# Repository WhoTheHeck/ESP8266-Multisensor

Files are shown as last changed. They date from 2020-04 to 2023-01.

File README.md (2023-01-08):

# ESPHome based multisensor



## Overview

Multisensor measuring temperature, humidity, air quality, brightness and movement. ESP board is a NodeMCU v2; Sensors are: SHT31, CCS811, BH1750 and AM312. An RGB LED indicates the air quality (good to bad or high humidity) whenever movement is detected. Using 3pin JST connectors three external sensors, running off of 3V can be attached. Two are digital only, one can be analog.
Components fit a standard 70x50mm prototype PCB. If you are the super-DIY-person everything can be soldered and wired up on a prototype PCB. If you want to avoid soldering too much and want to avoid wiring mistakes grab the PCB files, get PCBs manufactured and only solder the sensor modules.  



## Case

Case is intended to be 3d printed. Sensors sit in indentations in printed top part, which requires lots of support structures for 3D printing. A simplified version that can be printed upside down is possible, but looks less nice. The case measures 76x56x20mm. Everything gets soldered onto the PCB, placed into the case, backside gets screwed onto the wall, frontcase snapfits in place.  



## PCB

The PCB was intended to be hand solderable on a 70x50mm prototype-PCB. It's possible but time consuming. If more than one or two boards are required consider sending PCB files to a manufacturer of your choice. Therefore, the traces are held compatible to be used as an exact hand solder guide and are also fabrication ready. That results in some unnecessary vias.
Dependent on the position of a component hand soldering starts from one or the other side and sometimes an immediate layer change is required. For a manufactured board these additional vias are no problem.
A jumper can be used for changing one of the external sensors from digital to analog-in.

For manual soldering top traces are:  
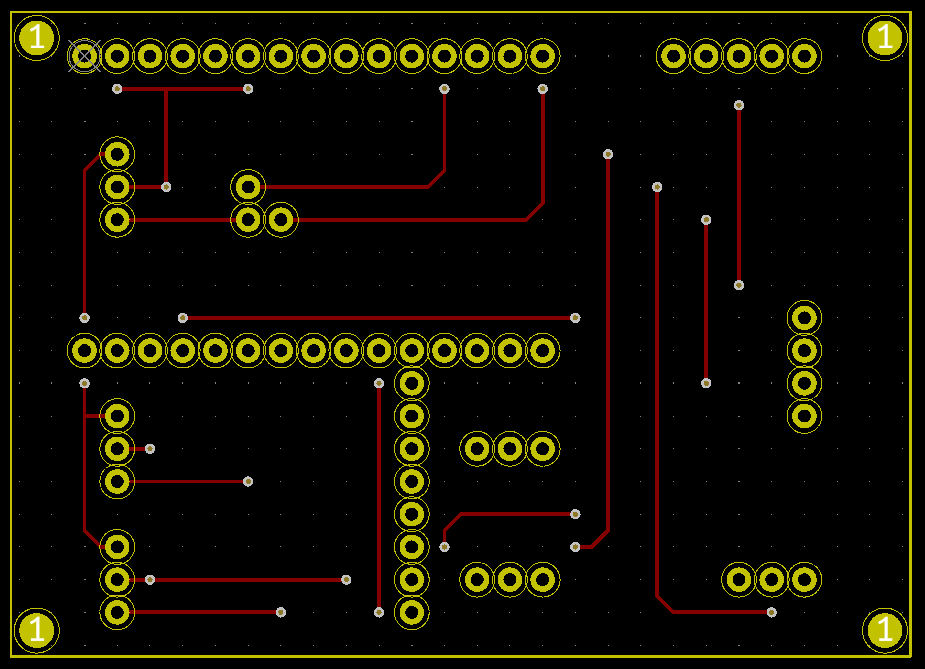
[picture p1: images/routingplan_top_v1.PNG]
  
bottom traces are:  
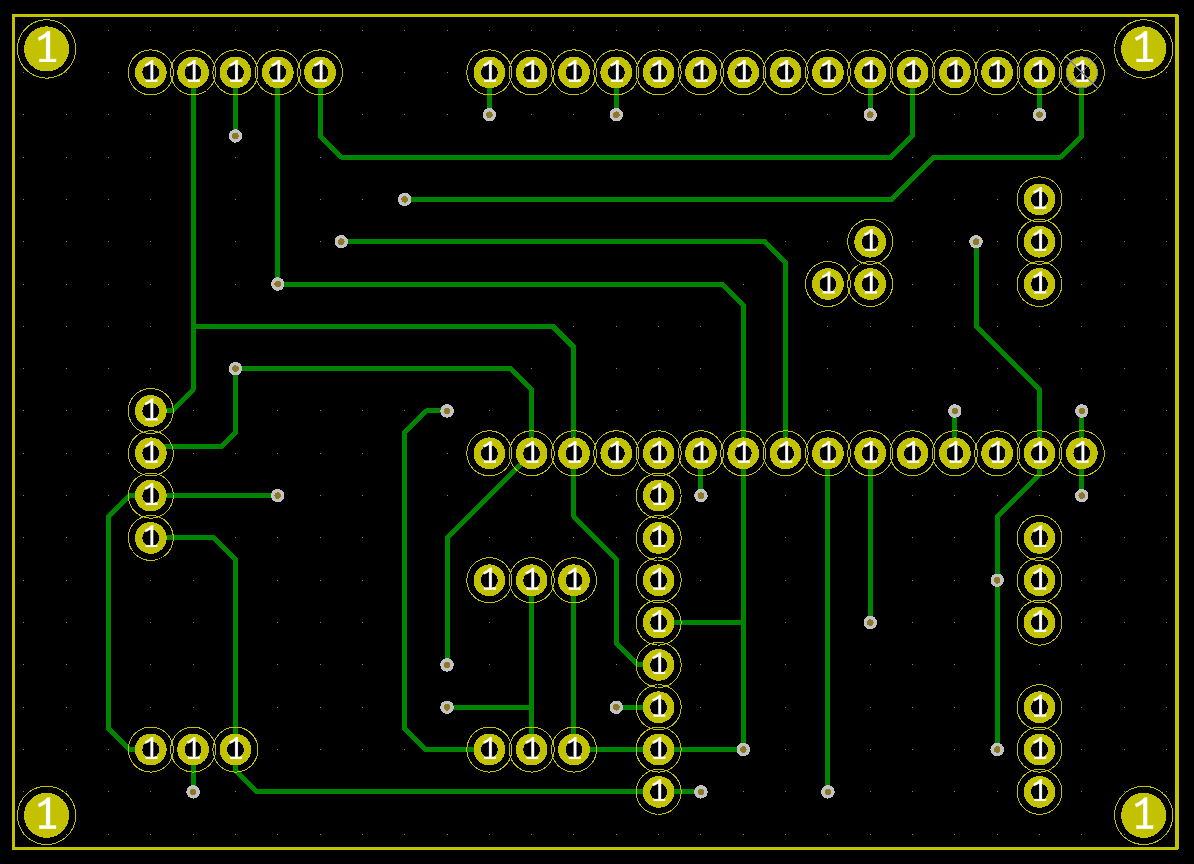
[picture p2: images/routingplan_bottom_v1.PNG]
  
Use isolating tape / kapton tape on PCB to avoid shorts between both layers.

## Assembly

- 3D print the 3 parts: case front, case back and JST assembly guide
- get the PCBs (manufactured or DIYed)
- solder copper wire through JST-connector solder points  

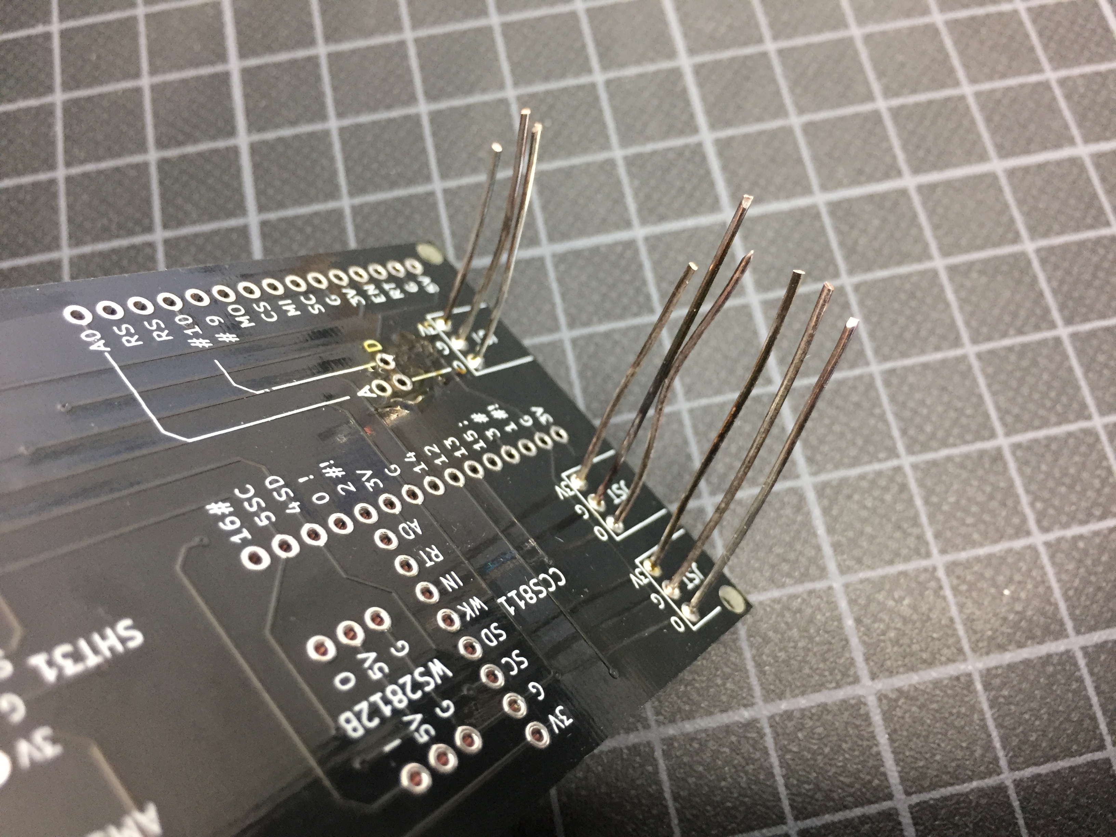
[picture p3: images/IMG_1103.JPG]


- place JST-connectors in assembly guide, place the PCB in there too  

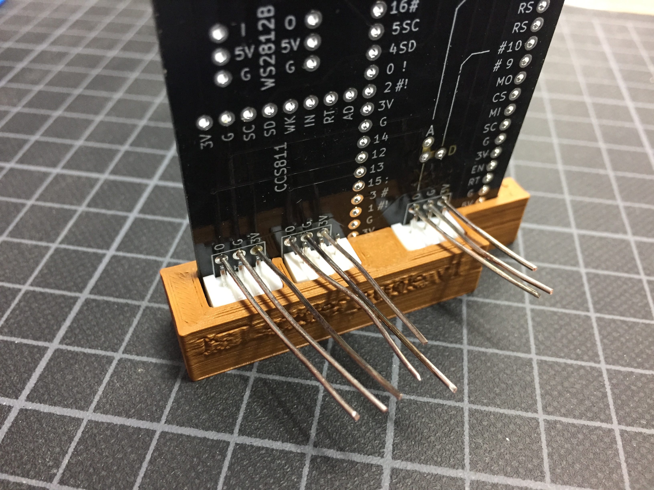
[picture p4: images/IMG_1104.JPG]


- solder JSTs to copper wire, cut off excess
- solder 3 pin header contacts for analog/digital select, place jumper accordingly; alternatively solder bridge  

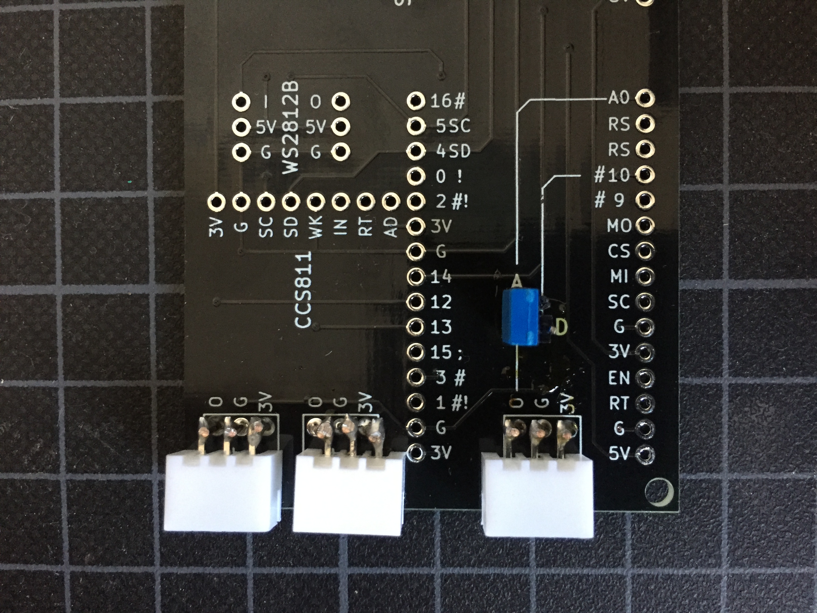
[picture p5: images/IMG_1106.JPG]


- solder sensor-modules, watch out that sensors face upright
- dependent on your AM312 pin headers can have the plastic piece so that its height will be increased. in that case remove the plastic of the pin header  

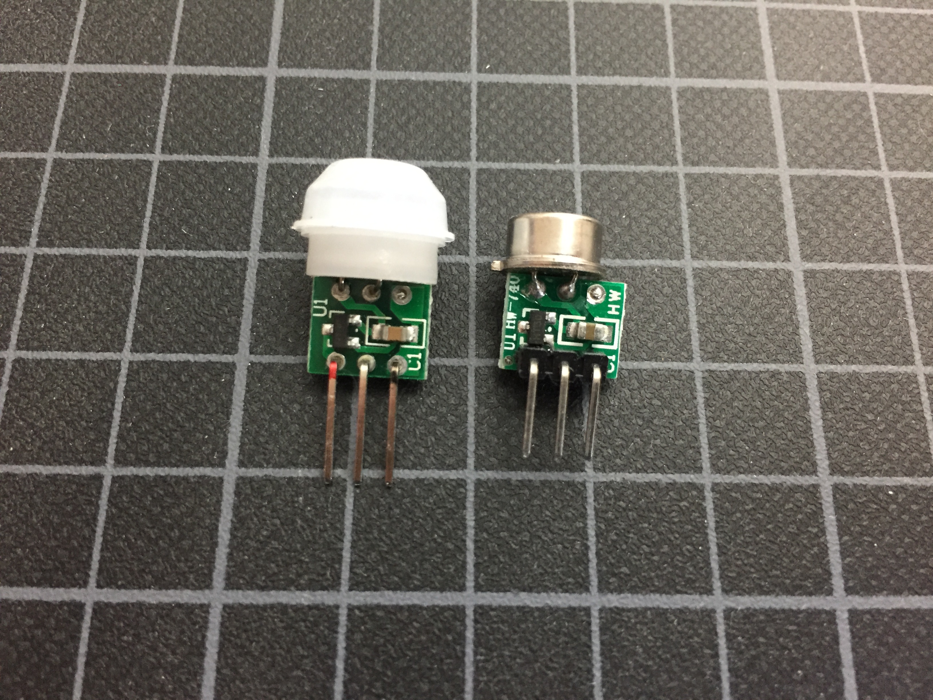
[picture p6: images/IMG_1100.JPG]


- solder sensor-modules and NodeMCU to PCB  

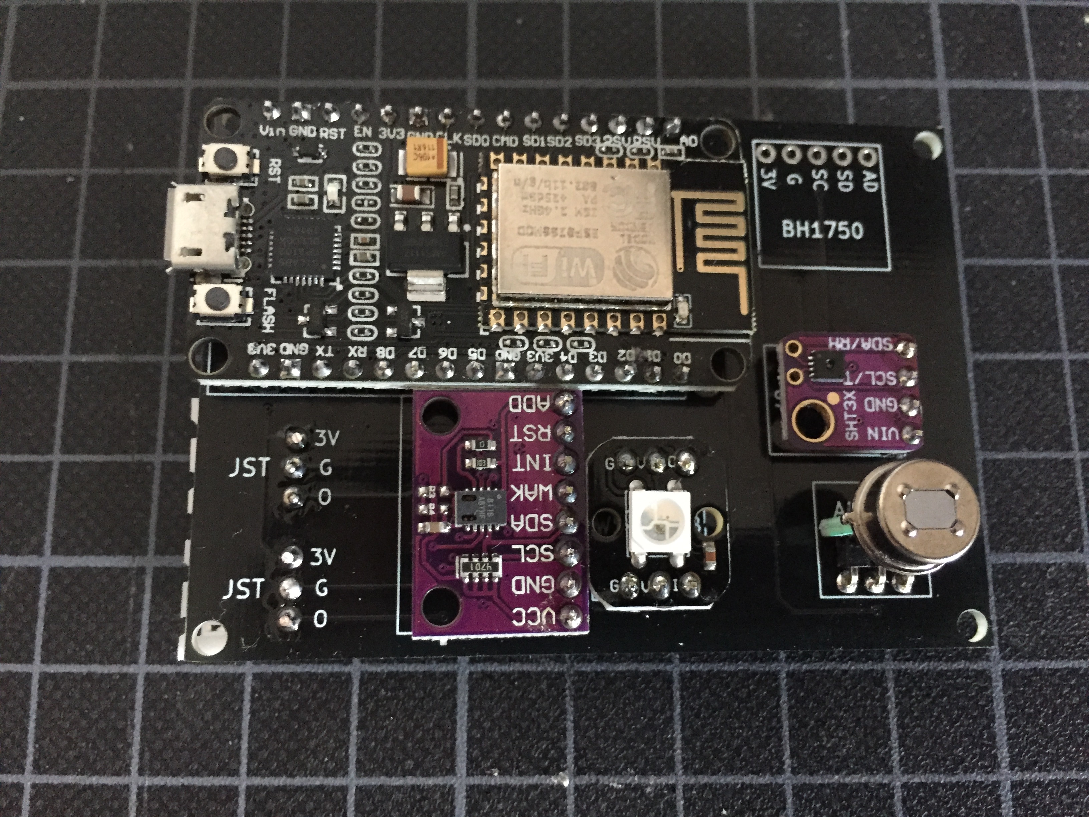
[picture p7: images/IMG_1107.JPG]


- place LED lens and light-sensor lens in case  

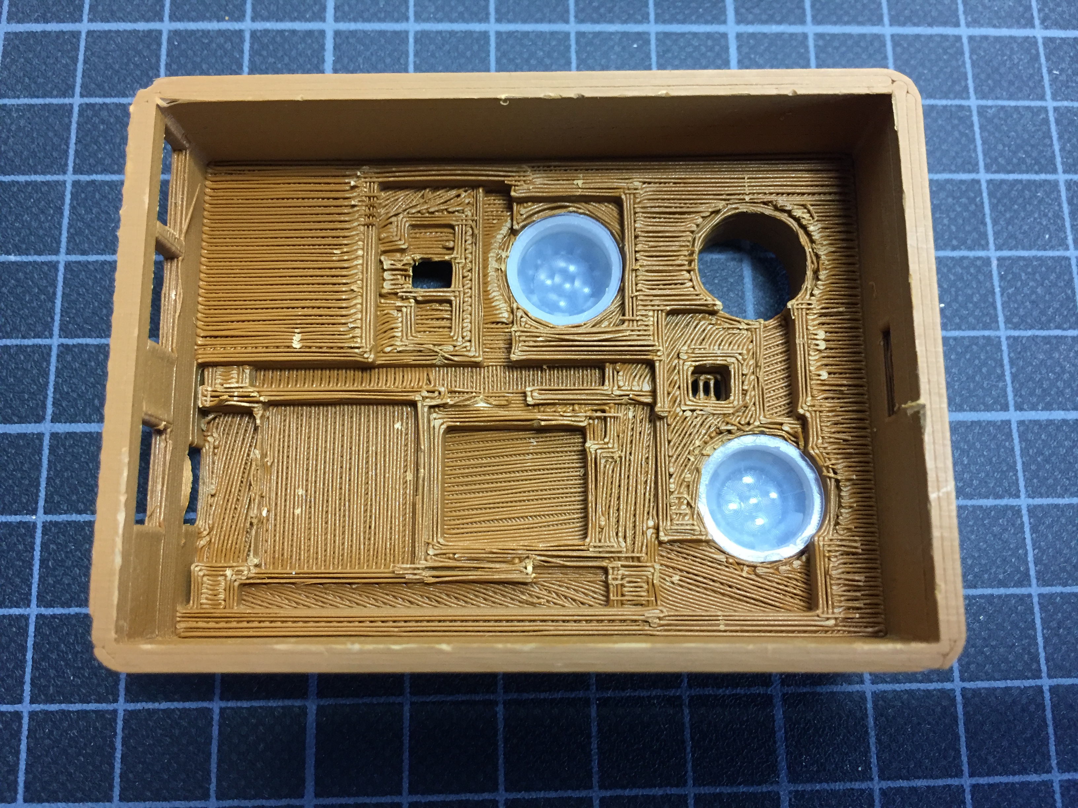
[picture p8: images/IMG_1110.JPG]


- remove lens from AM312
- put PCB in place
- put lens on AM312  

Done.  
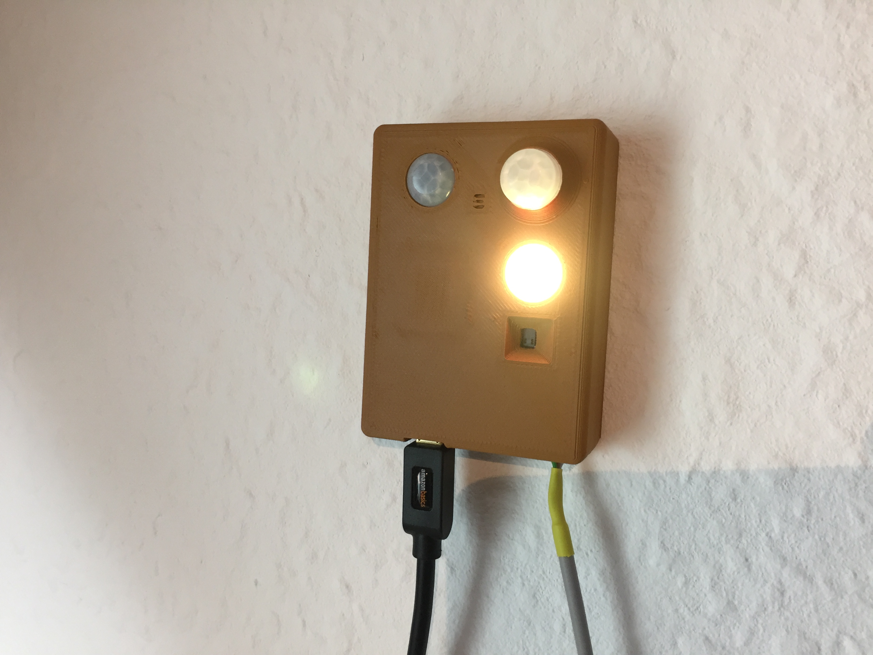
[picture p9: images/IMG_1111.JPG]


## Software

- create new sensor in ESPHome, settings aren't important here
- grab code from yaml-file, click "edit" for sensor in ESPHome, copy paste code - change according to your needs (e.g. make sure to enter your wifi-settings. I recommend to use the secrets-editor in ESPHome by clicking the three vertical dots in the very top right.)
- click the three vertical dots right of your sensor, click "compile", wait until it finishes, download binary
- get ESPHome-Flasher (google), connect Multisensor to your PC, make sure to use a cable with data lines!
- if the sensor doesn't get recognized make sure to have the driver for the CP210x USB-UART-controller installed
- in ESPHome-Flasher select correct serial port, select binary file, flash ESP  

Done. If everything works correct you will see the sensor-log. From now on you can do modifications to the code over wifi.

## External Sensors

There are 3 JST connectors usable for simple external sensors running off of 3V. They can be used for super tiny 10x17x8mm DIY wired window/door contacts with hall effect sensors. (ToDo --> add to project)
One of the external sensors can be analog. Therefore, setting the jumper accordingly is required.

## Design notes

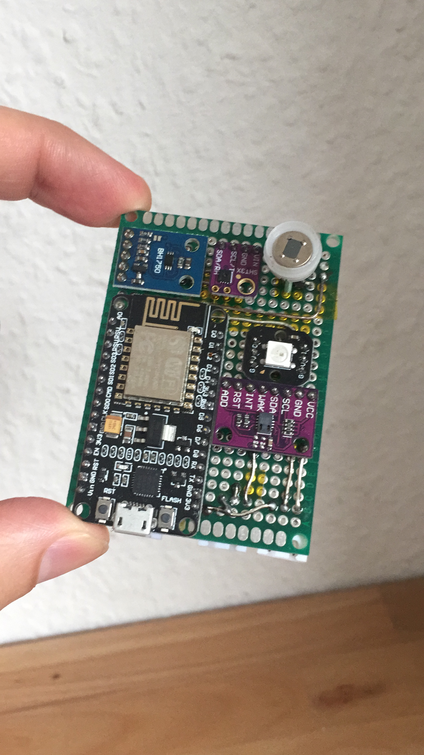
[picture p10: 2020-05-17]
images/YKGE3823.JPG

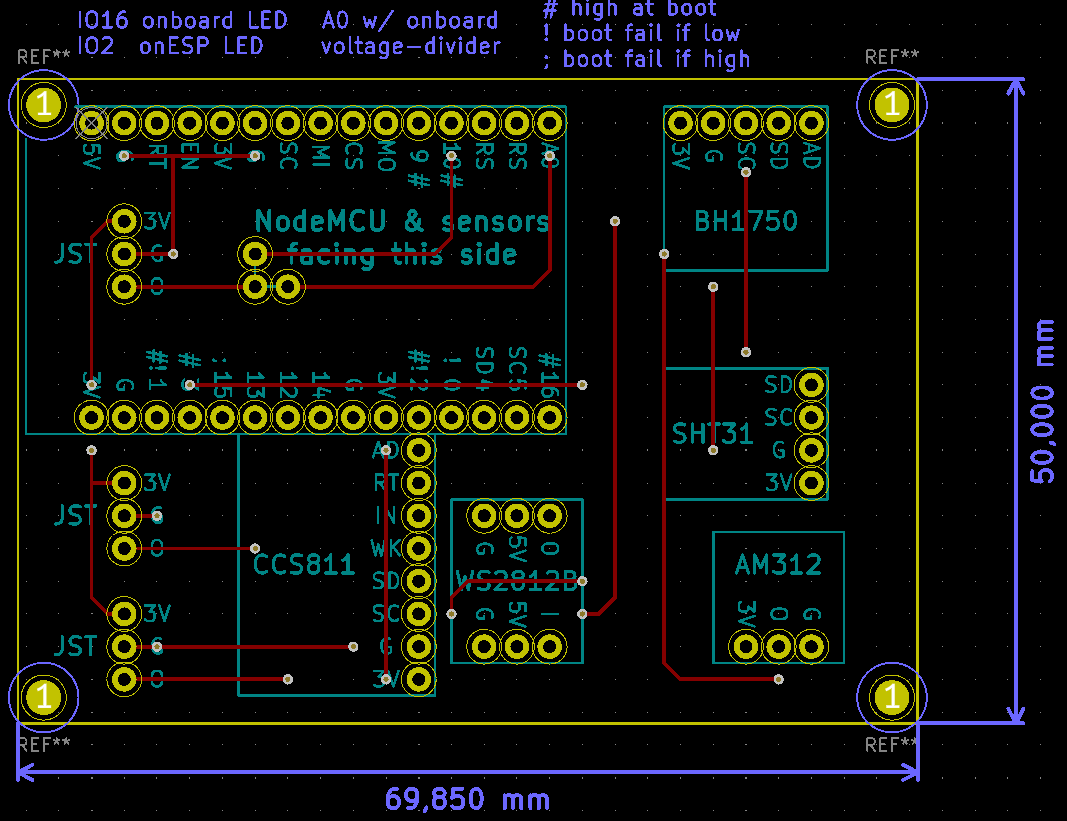
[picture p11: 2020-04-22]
images/routingplan_top+text_v1.PNG

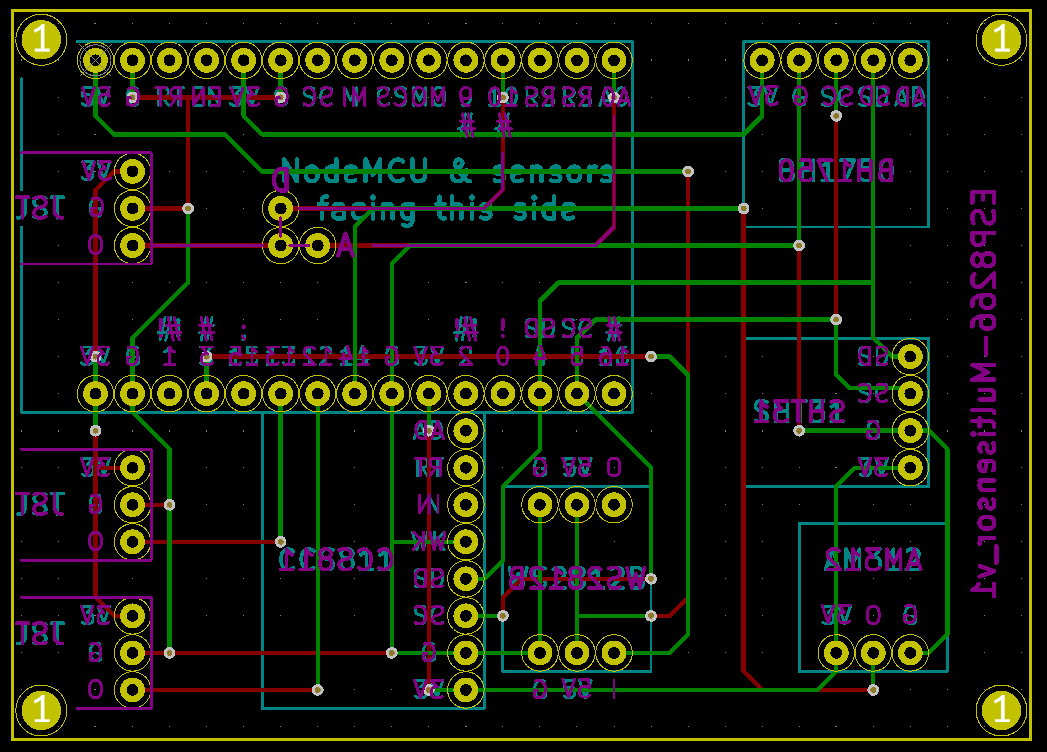
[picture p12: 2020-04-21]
images/routingplan_v1.PNG

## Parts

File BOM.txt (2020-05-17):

# BOM

1x NodeMCU v2
1x SHT31
1x CCS811
1x BME280
1x AM312
1x WS2812B 1-Bit Module - RGB LED
1x PCB
1x Case top (3D printed)
1x Case bottom (3D printed)
1x JST assembly guide (3d printed)
3x 3 pin JST
2x fresnel lenses (type 13120) (1 as LED diffusor, 1 as lightsensor cover)
copper wire, solder tools

optional:
3x pinheader-contacts (alternatively solderbridge on PCB)

under evaluation: fresnel lenses.
type 023115 could potentially be a replacement for AM312 Lens -> should improve range
type 13120F2 should have same dimensions as 13120 with slightly improved range.
In that case the lenses work: use the original AM312 lens for the LED diffusor, get only one more 12130 lens for the light sensor, use the 023115 lens for the AM312.

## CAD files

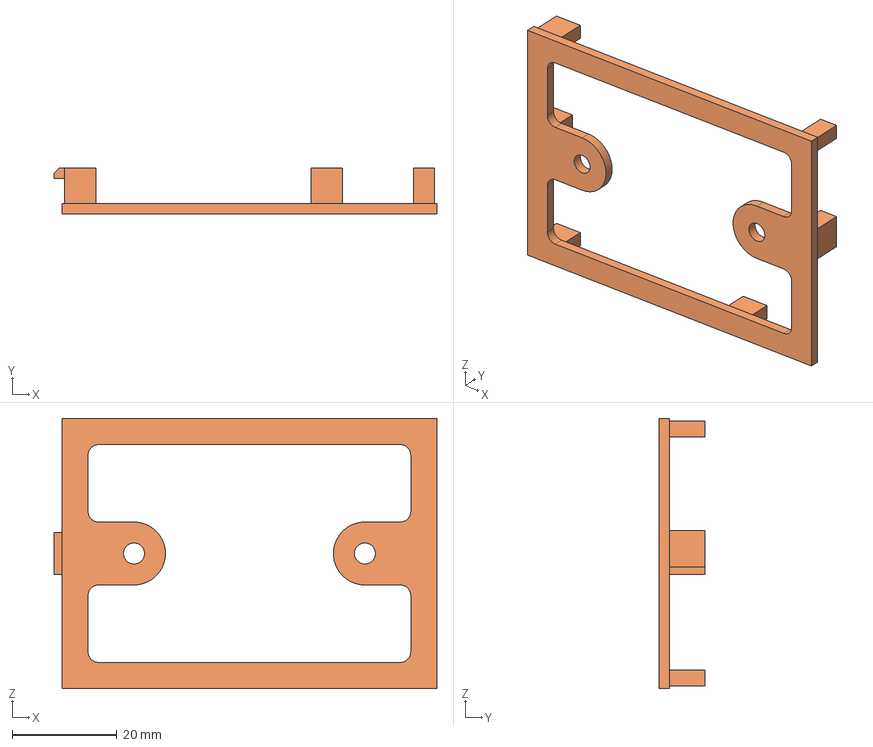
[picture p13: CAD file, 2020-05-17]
caseback_1v0.stp
73.0 x 8.70 x 51.5 mm

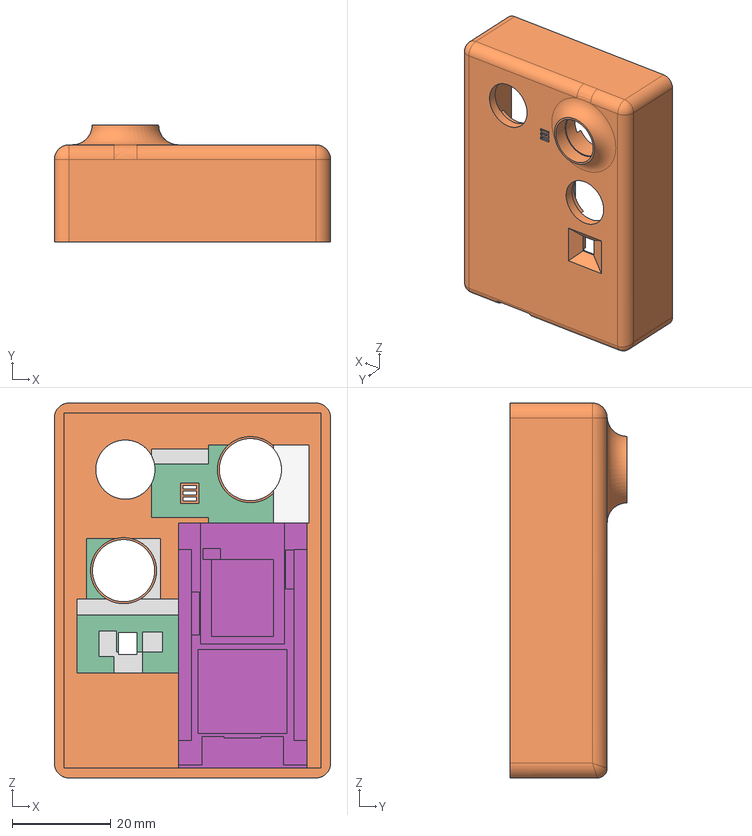
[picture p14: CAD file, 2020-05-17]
casefront_1v0.stp
56.0 x 23.7 x 76.0 mm

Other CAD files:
Caseback_1v0.stl
casefront_1v0.stl

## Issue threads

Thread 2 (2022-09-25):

WS2812B breakout board

silviudc, 2022-09-25:
Hi, I'm having trouble finding this particular type of led breakout board you have:
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

Everything I found on a breakout board has the pins in the wrong order so it won't work on the PCB (which I have already ordered)
Any suggestions? Or could you share the exact model number and place you purchased them from?

Thanks

WhoTheHeck, 2022-09-27:
I got mine from ebay. Searching for "WS2812B 1-Bit Module" I still find this exact board from different sellers, typically located in China.

silviudc, 2022-10-02:
Great, thanks for the suggestion, bought a few :)

Closed 2022-10-02.

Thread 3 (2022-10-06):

Fresnel lens size

silviudc, 2022-10-06:
Any idea which lens size fits perfectly in the 3d printed case?

The one linked [here ](https://www.aliexpress.com/item/4000851822692.html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 )has three sizes.

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

WhoTheHeck, 2022-10-19:
Sorry I seem to not get notifications for new issues. Can you add the information for which lens is the correct one if you already found the answer? 😇

silviudc, 2022-10-19:
I went for the middle one 12.8 as that is the size of the lens some of the am311 sensors I have, will see if it fits when it arrives.

Closed 2022-10-15.

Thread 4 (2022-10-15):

ESP32 board

silviudc, 2022-10-15:
Any chance to update this to accommodate the 30 pin esp32 boards?
Like these ones: https://smile.amazon.co.uk/gp/product/B0814WGPVY/ref=ppx_yo_dt_b_asin_title_o02_s00?ie=UTF8&psc=1
Super handy for using the new BT proxy integrations.

WhoTheHeck, 2022-10-19:
An ESP32 board would indeed be a nice upgrade since these also seem to have a more stable wifi connection besides the BT benefit. Unfortunetly the pinouts are too different for a quick fix. The kicad_pcb file in the PCB folder would have to be rerouted.

IMO a new ESP32-based board with more and better sensors (e.g. a better CCS811 alternative) would be preferable.

silviudc, 2022-10-19:
Yes and no with the ESP32 and BT proxy, it seems like BT proxy uses most of the memory of the ESP32 so with this many sensors might not even work.
For example BT proxy and an ILI9341 screen just doesn't work, either one or the other but not both.
Might be ok for temp/hum/lux/motion sensors and BT proxy but not guaranteed.

silviudc, 2022-11-04:
Decided to add make a bit of a HAT for the sensors, in case any of the fail, unplug and replace
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
Still fits in the original STL but need to work out something for the back cover

WhoTheHeck, 2022-11-04:
nice to see another one is made!
not sure if one of the sensors ever will break, but also for disassembly it is definetly a good idea.
I could adjust the model to accomodate for the additonal length. Basically just make it a little deeper.

WhoTheHeck, 2022-11-04:
> Yes and no with the ESP32 and BT proxy, it seems like BT proxy uses most of the memory of the ESP32 so with this many sensors might not even work. For example BT proxy and an ILI9341 screen just doesn't work, either one or the other but not both. Might be ok for temp/hum/lux/motion sensors and BT proxy but not guaranteed.

I realized that issue with an ESP32-Cam module the other day too, but thought it might be due to the additonal camera stream. Not sure if any of the ESP32's would have enough capability to fulfill all the functions then.

silviudc, 2022-11-04:
I have seen temp&hum, maybe co2 sensors that can fail but at the same time all the parts are cheap enough (until you add them up ;))
Other thing I was thinking of was ventilation but the esp8266 doesn't get as hot as the esp32 so maybe ok, still wouldn't hurt to have a few holes on the back cover.

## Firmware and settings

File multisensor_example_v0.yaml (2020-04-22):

esphome:
  name: room_sensor
  platform: ESP8266
  board: nodemcuv2
  # arduino_version: 2.6.2

wifi:
  ssid: !secret ssidname
  password: !secret pswrd
  manual_ip:
    static_ip: xxxxxxxxxxxx
    gateway: xxxxxxxxxxxx
    subnet: xxxxxxxxxxxx
    dns1: xxxxxxxxxxxx
    dns2: xxxxxxxxxxxx

  # Enable fallback hotspot (captive portal) in case wifi connection fails
  ap:
    ssid: "room-Senor Fallback Hotspot"
    password: "SdI0kd54Zpw0"

# Enable logging
logger:
					  
  logs:
    i2c: debug

# Enable Home Assistant API
api:

ota:

i2c:
  id: bus_a

globals:
  - id: iaq_index
    type: int
    restore_value: no
    initial_value: '0'

sensor:
#  - platform: adc
#    pin: A0
#    name: "room Input"
#    update_interval: 60s
  - platform: sht3xd
    # address: 0x44
    temperature:
      name: "room Temp"
      filters:
        - offset: -2.7  # was -1
      id: temp
    humidity:
      name: "room humidity"
      #filters:
        #- offset: +0.8
      id: humi
    update_interval: 60s
  - platform: ccs811
    eco2:
      name: "room eCO2"
      id: eco2
      filters:
      - lambda: |-
          if (x >= 50000) return 1;
          else return x;
    tvoc:
      name: "room TVOC"
      id: tvoc
      filters:  # filters high values that are reported after startup
      - lambda: |-
          if (x >= 50000) return 1;
          else return x;
    temperature: temp
    humidity: humi
    baseline: 0x7B7B
    # address: 0x5A
    update_interval: 60s
  - platform: wifi_signal
    name: "room Wifi"
    update_interval: 60s
  - platform: bh1750
    name: "room Helligkeit"
    id: brightness
    unit_of_measurement: lx
    # address: 0x23
    update_interval: 60s

binary_sensor:
  - platform: gpio
    pin: 12
    name: "room window"
    id: window
    device_class: window
    filters:
      - delayed_off: 500ms
      - delayed_on: 500ms
#  - platform: gpio
#    pin: 13
#    name: "room window 2"
#    id: window2
#    device_class: window
#    filters:
#      - delayed_off: 500ms
#      - delayed_on: 500ms
#  - platform: gpio
#    pin: 10
#    name: "room window 3"
#    id: window2
#    device_class: window
#    filters:
#      - delayed_off: 500ms
#      - delayed_on: 500ms
  - platform: gpio
    pin: 14
    name: "room Bewegung"
    id: motion
    device_class: motion
    filters:
      - delayed_off: 5s
    on_press:
      # order defines priority! low position == higher prio.
      - if:
          condition:
            and:
              - binary_sensor.is_on: motion
              - text_sensor.state:
                  id: airqual
                  state: "Excellent"
          then:
            - script.execute: ledgreen
      - if:
          condition:
            and:
              - binary_sensor.is_on: motion
              - text_sensor.state:
                  id: airqual
                  state: "Good"
          then:
            - script.execute: ledgreenish
      - if:
          condition:
            and:
              - binary_sensor.is_on: motion
              - sensor.in_range:
                  id: humi
                  above: 70
                  below: 100
          then:
            - script.execute: ledblue
      - if:
          condition:
            and:
              - binary_sensor.is_on: motion
              - text_sensor.state:
                  id: airqual
                  state: "Moderate"
          then:
            - script.execute: ledyellow
      - if:
          condition:
            and:
              - binary_sensor.is_on: motion
              - text_sensor.state:
                  id: airqual
                  state: "Poor"
          then:
            - script.execute: ledorange
      - if:
          condition:
            and:
              - binary_sensor.is_on: motion
              - text_sensor.state:
                  id: airqual
                  state: "Unhealty"
          then:
            - script.execute: ledred
  - platform: status
    name: "room ESP Status"

switch:
  - platform: restart
    name: "room ESP Restart"
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

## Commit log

2020-04-13 Create multisensor_example_v0.yaml
    current yaml file
2020-04-21 initial PCB files
    pictures usable for hand soldering everything onto 70x50mm prototype.
    Kicad-pcb file for sending to manufacturer.
    [ESP8266-Multisensor_v1.kicad_pcb]
2020-04-21 correct picture
    picture showing additional NodeMCU pin information
2020-04-22 PCB bugfixes
    increased drill hole size and pad size
    made silkscreen nicer
    changed jumper to not only work with pin header but also solder bridge
    [ESP8266-Multisensor_v1.kicad_pcb]
2020-04-22 corrected pin numbers, added features
    improved pin assignment
    added all current options
    added onboard leds, although they are not visible once assembled!
    [multisensor_example_v0.yaml]
2020-05-17 organize, extend readme
    added assembly instructions, added pictures, added new case, added renders, added pcb gerber-files
    [Caseback_1v0.stl, ESP8266-Multisensor_v1.kicad_pcb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]
